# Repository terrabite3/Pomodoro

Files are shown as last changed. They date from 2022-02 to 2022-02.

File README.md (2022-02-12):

# Pomodoro

This is a tomato-shaped timer that counts down from 25 minutes.

## Hardware

* ATmega328p or compatible (I used ATmega8 due to supply chain issues)
* USB Micro-B power
* Four-digit 7-segment multiplexed display with colon LEDs
* Reset button
* Wheel potentiometer to adjust brightness
* Extra GPIO is exposed on a header
* Designed to be mostly assembled by JLCPCB

## Software

* Hard-coded 25 minute countdown
* Flashes 00:00 for one minute after countdown finishes
* Full shutdown after count is complete to save power
* Brightness adjustment goes down "off" to reduce visual distraction. At the start of the countdown, the display will start on and fade down to the selected brightness after 10 seconds. The flashing at the end of the countdown ignores the brightness setting.

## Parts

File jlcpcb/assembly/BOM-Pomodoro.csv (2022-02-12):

Comment | Designator | Footprint | LCSC
1k | R10 | R_0402_1005Metric | C11702
USB_B_Micro | J1 | USB_Micro-B_Amphenol_10118194_Horizontal | C132563
100n | C2,C3 | C_0402_1005Metric | C1525
15p | C4,C5 | C_0402_1005Metric | C1548
10u | C1 | C_0805_2012Metric | C15850
330 | R1,R11,R12,R2,R3,R4,R5,R6,R7,R8 | R_0402_1005Metric | C25104
10k | R9 | R_0402_1005Metric | C25744
2N7002 | Q1,Q2,Q3,Q4 | SOT-23 | C8545
Crystal_GND24 | Y1 | Crystal_SMD_3225-4Pin_3.2x2.5mm | C9002

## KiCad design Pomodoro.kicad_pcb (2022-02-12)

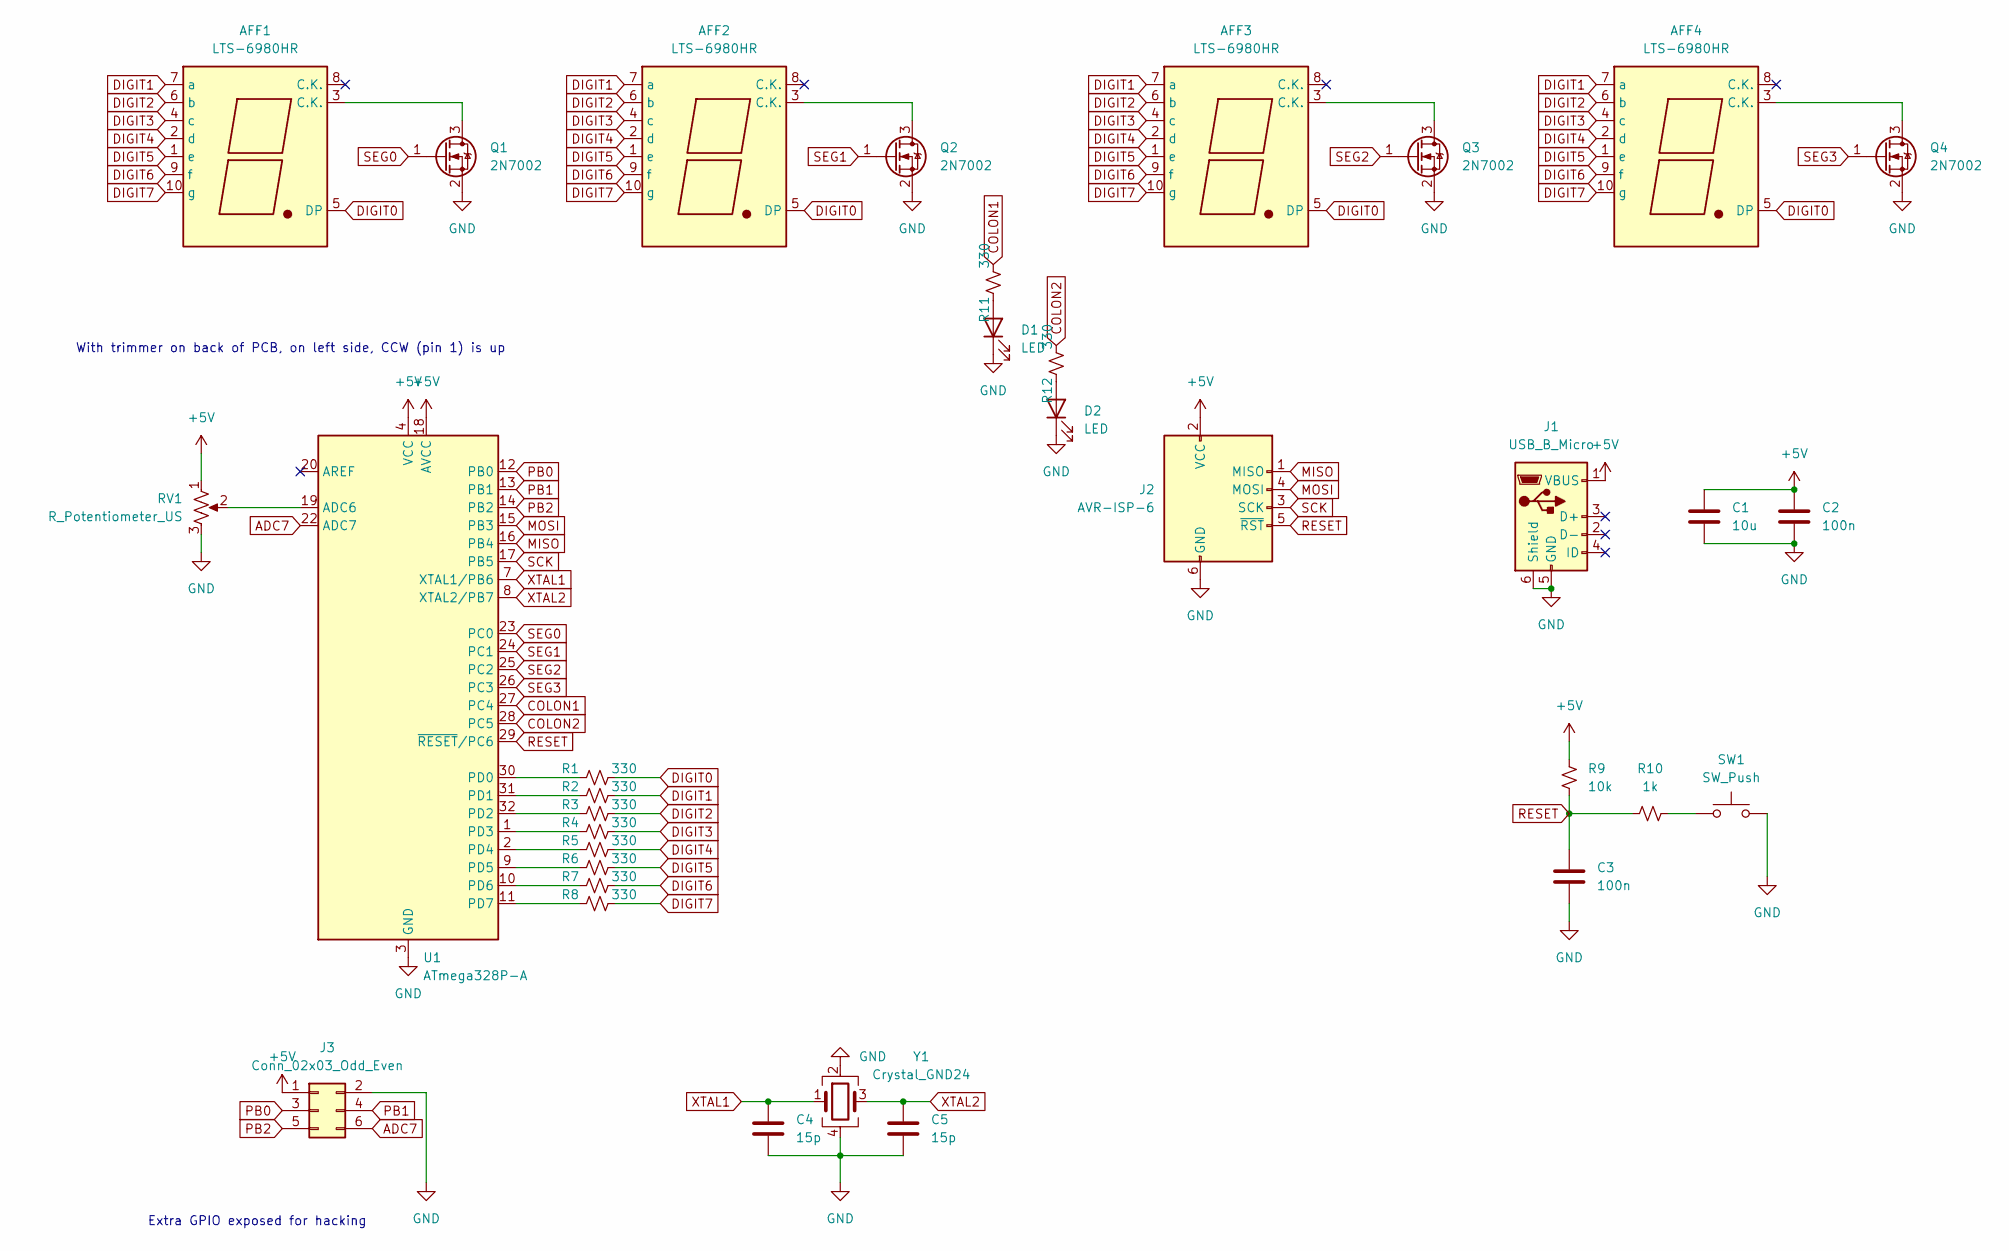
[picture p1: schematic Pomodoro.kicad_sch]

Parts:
AFF1, AFF2, AFF3, AFF4: LTS-6980HR; 7SegmentLED_LTS6760_LTS6780
C1: 10u; C_0805_2012Metric
C2, C3: 100n; C_0402_1005Metric
C4, C5: 15p; C_0402_1005Metric
D1, D2: LED; LED_D3.0mm
J1: USB_B_Micro; USB_Micro-B_Amphenol_10118194_Horizontal
J2: AVR-ISP-6; PinHeader_2x03_P2.54mm_Vertical_SMD
J3: Conn_02x03_Odd_Even; PinHeader_2x03_P2.54mm_Vertical_SMD
Q1, Q2, Q3, Q4: 2N7002; SOT-23
R1, R2, R3, R4, R5, R6, R7, R8, R11, R12: 330; R_0402_1005Metric
R9: 10k; R_0402_1005Metric
R10: 1k; R_0402_1005Metric
RV1: R_Potentiometer_US; Potentiometer_Bourns_3352T
SW1: SW_Push; SW_PUSH_6mm
U1: ATmega328P-A; TQFP-32_7x7mm_P0.8mm
Y1: Crystal_GND24; Crystal_SMD_3225-4Pin_3.2x2.5mm

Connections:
+5V: C1.1, C2.1, J1.1 (VBUS), J2.2 (VCC), J3.1, R9.2, RV1.1, U1.4 (VCC), U1.6 (VCC), U1.18 (AVCC)
ADC7: J3.6, U1.22 (ADC7)
COLON1: R11.2, U1.27 (PC4)
COLON2: R12.2, U1.28 (PC5)
DIGIT0: AFF1.5 (DP), AFF2.5 (DP), AFF3.5 (DP), AFF4.5 (DP), R1.2
DIGIT1: AFF1.7 (a), AFF2.7 (a), AFF3.7 (a), AFF4.7 (a), R2.2
DIGIT2: AFF1.6 (b), AFF2.6 (b), AFF3.6 (b), AFF4.6 (b), R3.2
DIGIT3: AFF1.4 (c), AFF2.4 (c), AFF3.4 (c), AFF4.4 (c), R4.2
DIGIT4: AFF1.2 (d), AFF2.2 (d), AFF3.2 (d), AFF4.2 (d), R5.2
DIGIT5: AFF1.1 (e), AFF2.1 (e), AFF3.1 (e), AFF4.1 (e), R6.2
DIGIT6: AFF1.9 (f), AFF2.9 (f), AFF3.9 (f), AFF4.9 (f), R7.2
DIGIT7: AFF1.10 (g), AFF2.10 (g), AFF3.10 (g), AFF4.10 (g), R8.2
GND: C1.2, C2.2, C3.2, C4.2, C5.2, D1.1 (K), D2.1 (K), J1.5 (GND), J1.6 (Shield), J2.6 (GND), J3.2, Q1.2 (S), Q2.2 (S), Q3.2 (S), Q4.2 (S), RV1.3, SW1.2, U1.3 (GND), U1.5 (GND), U1.21 (GND), Y1.2, Y1.4
MISO: J2.1 (MISO), U1.16 (PB4)
MOSI: J2.4 (MOSI), U1.15 (PB3)
unnamed: AFF1.3 (C.K.), Q1.3 (D)
unnamed: AFF2.3 (C.K.), Q2.3 (D)
unnamed: AFF3.3 (C.K.), Q3.3 (D)
unnamed: AFF4.3 (C.K.), Q4.3 (D)
unnamed: D1.2 (A), R11.1
unnamed: D2.2 (A), R12.1
unnamed: R10.2, SW1.1
unnamed: R4.1, U1.1 (PD3)
unnamed: R5.1, U1.2 (PD4)
unnamed: R6.1, U1.9 (PD5)
unnamed: R7.1, U1.10 (PD6)
unnamed: R8.1, U1.11 (PD7)
unnamed: RV1.2, U1.19 (ADC6)
unnamed: R1.1, U1.30 (PD0)
unnamed: R2.1, U1.31 (PD1)
unnamed: R3.1, U1.32 (PD2)
PB0: J3.3, U1.12 (PB0)
PB1: J3.4, U1.13 (PB1)
PB2: J3.5, U1.14 (PB2)
RESET: C3.1, J2.5 (~RST), R9.1, R10.1, U1.29 (~RESET/PC6)
SCK: J2.3 (SCK), U1.17 (PB5)
SEG0: Q1.1 (G), U1.23 (PC0)
SEG1: Q2.1 (G), U1.24 (PC1)
SEG2: Q3.1 (G), U1.25 (PC2)
SEG3: Q4.1 (G), U1.26 (PC3)
XTAL1: C4.1, U1.7 (XTAL1/PB6), Y1.1
XTAL2: C5.1, U1.8 (XTAL2/PB7), Y1.3

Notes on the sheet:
Extra GPIO exposed for hacking
With trimmer on back of PCB, on left side, CCW (pin 1) is up

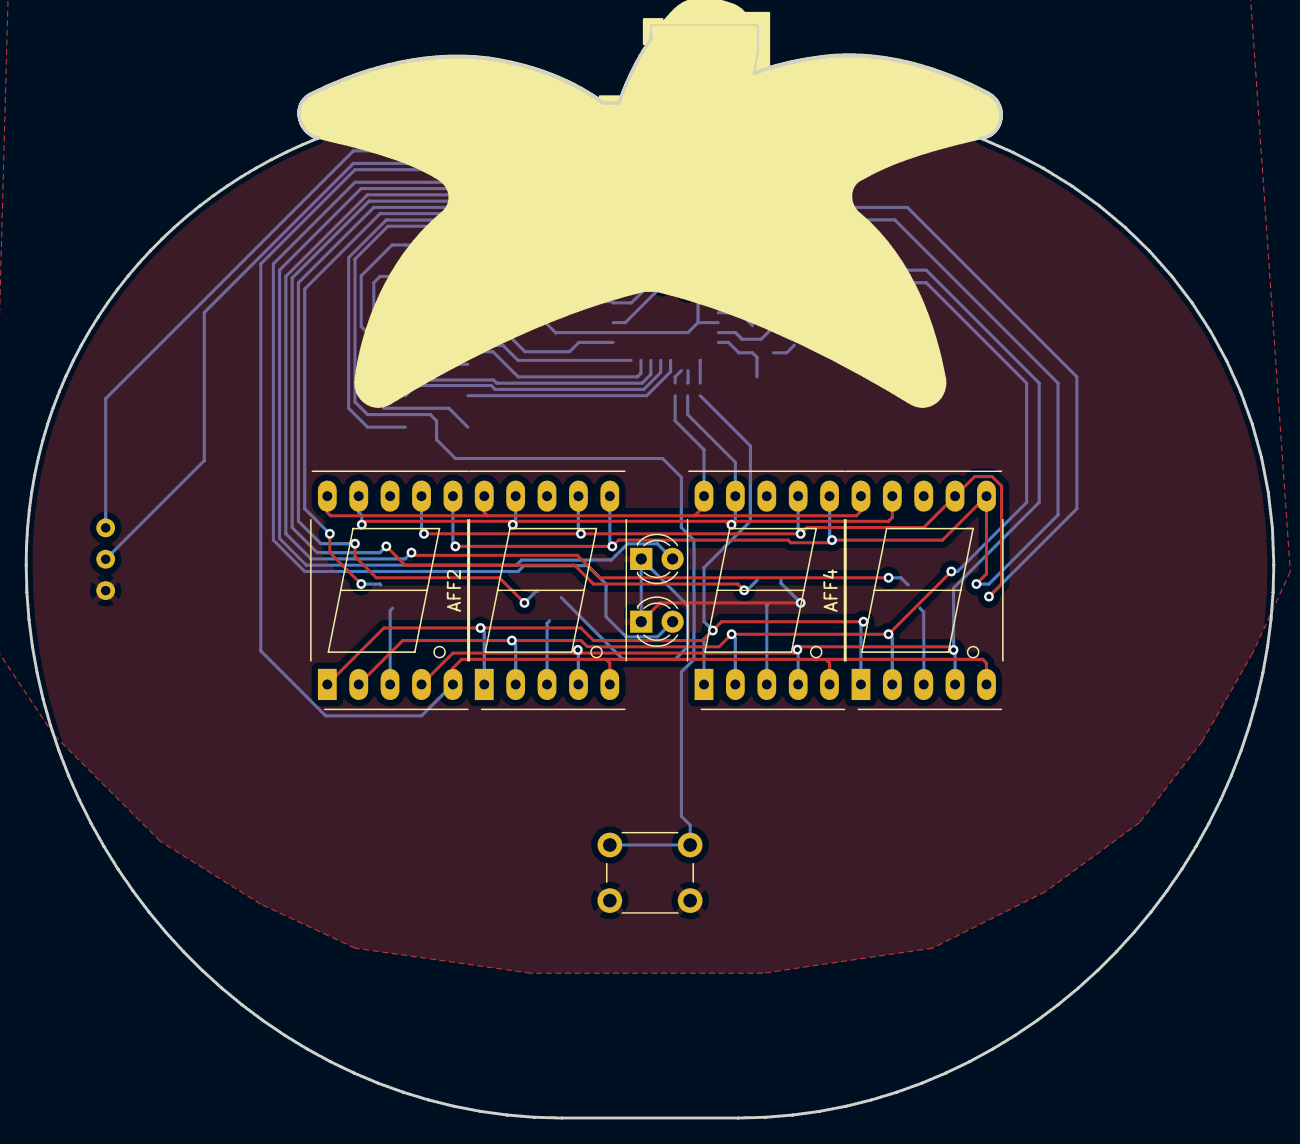
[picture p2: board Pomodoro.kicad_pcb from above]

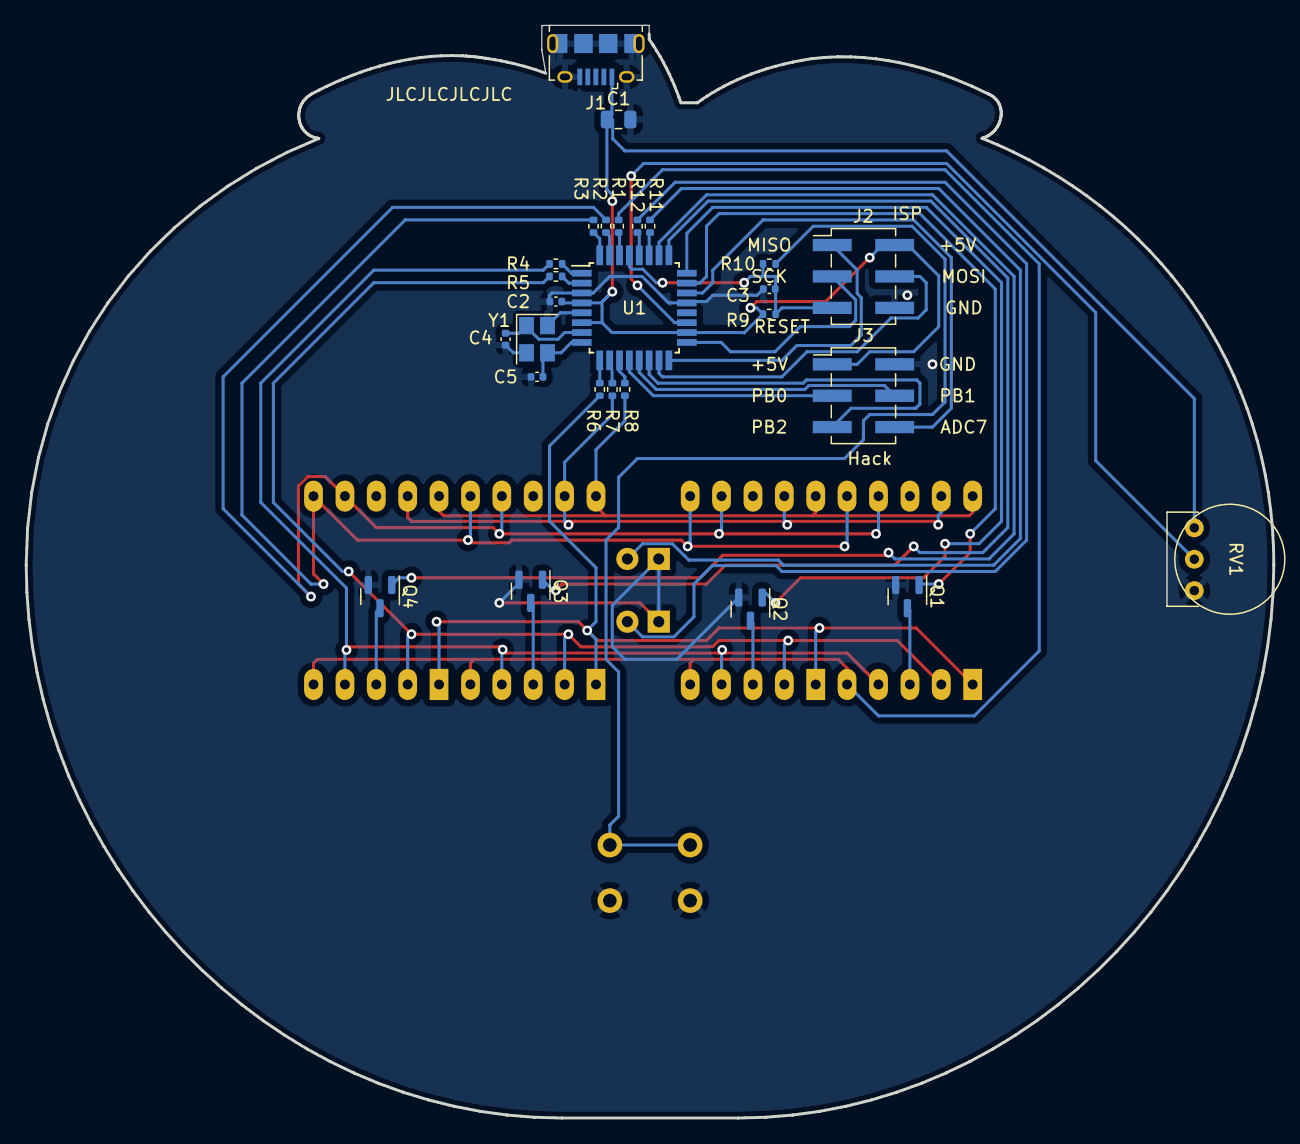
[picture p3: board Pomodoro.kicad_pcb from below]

Board: 2 copper layers, 101.0 x 88.4 mm, 34 parts (27 on the bottom side), 42 nets.

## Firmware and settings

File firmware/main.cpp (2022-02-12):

#include <avr/io.h>
#include <avr/interrupt.h>
#include <avr/sleep.h>

#include <util/delay_basic.h>

/* Pin map

PB0     hack header
PB1     hack header
PB2     hack header
PB3     MOSI (JTAG header)
PB4     MISO (JTAG header)
PB5     SCK (JTAG header)
PB6     XTAL
PB7     XTAL

PC0     SEG0
PC1     SEG1
PC2     SEG2
PC3     SEG3
PC4     COLON1
PC5     COLON2
PC6     RESET (button)

PD0     DIGIT0
...     ...
PD7     DIGIT7

ADC6    pot
ADC7    hack header

*/

#define RESET_TIME 25 * 60

volatile int16_t countdown = RESET_TIME;

ISR(TIMER1_COMPA_vect)
{
    countdown--;
}

void setupTimer()
{
    // setup the timer to fire every 1 second
    
    // Timer count calculated with https://eleccelerator.com/avr-timer-calculator/
    // 12 MHz, 16-bit, Prescaler = Clk/256, Real Time = 1 second
    TCCR1A = 0;         // Nothing needed here
    TCCR1B =  1<<WGM12  // CTC mode (clear timer on compare match)
            | 1<<CS12;  // Clk/256 prescaler
    OCR1A = 46875;

    TIMSK = 1<<OCIE1A;  // Enable the interrupt for output compare A match

    sei(); // Enable global interrupt flag
}

uint8_t digitCode0 = 0;
uint8_t digitCode1 = 0;
uint8_t digitCode2 = 0;
uint8_t digitCode3 = 0;

void noDigit()
{
    PORTC = 0;
}

void nextDigit()
{
    static uint8_t digit = 0;

    digit = (digit + 1) % 4;

    // Reset segment drivers
    PORTC &= ~(1<<PC0 | 1<<PC1 | 1<<PC2 | 1<<PC3);

    switch (digit)
    {
    case 0:
        PORTC |= 1<<PC0;
        PORTD = digitCode0;
        break;
    case 1:
        PORTC |= 1<<PC1;
        PORTD = digitCode1;
        break;
    case 2:
        PORTC |= 1<<PC2;
        PORTD = digitCode2;
        break;
    case 3:
        PORTC |= 1<<PC3;
        PORTD = digitCode3;
        break;
    }
}

uint8_t numberToCode(uint8_t number)
{
    switch (number)
    {
    case 0:
        return 0b01111110;
    case 1:
        return 0b00001100;
    case 2:
        return 0b10110110;
    case 3:
        return 0b10011110;
    case 4:
        return 0b11001100;
    case 5:
        return 0b11011010;
    case 6:
        return 0b11111010;
    case 7:
        return 0b00001110;
    case 8:
        return 0b11111110;
    case 9:
        return 0b11011110;
    case 10: // All off
        return 0b00000000;
    default: // Light decimal point to indicate error
        return 0b00000001;
    }
}

void updateDigits()
{
    // Normal behavior
    if (countdown >= 0)
    {
        uint8_t minutes = countdown / 60;
        uint8_t minutesOnes = minutes % 10;
        uint8_t minutesTens = minutes / 10;

        uint8_t seconds = countdown % 60;
        uint8_t secondsOnes = seconds % 10;
        uint8_t secondsTens = seconds / 10;

        digitCode0 = numberToCode(minutesTens);
        digitCode1 = numberToCode(minutesOnes);
        digitCode2 = numberToCode(secondsTens);
        digitCode3 = numberToCode(secondsOnes);
    }
    // Countdown has underflowed, less than a minute ago
    // Blink 00:00
    else if (countdown >= -60) 
    {
        if (countdown % 2)
        {
            digitCode0 = numberToCode(10);
            digitCode1 = numberToCode(10);
            digitCode2 = numberToCode(10);
            digitCode3 = numberToCode(10);
        }
        else
        {
            digitCode0 = numberToCode(0);
            digitCode1 = numberToCode(0);
            digitCode2 = numberToCode(0);
            digitCode3 = numberToCode(0);
        }
    }
    else
    {
        // Go into low power mode until the reset button is pressed
        cli(); // Disable interrupts

        // Turn off all LEDs and set pins as inputs
        PORTC = 0;
        PORTD = 0;
        DDRC = 0;
        DDRD = 0;

        set_sleep_mode(SLEEP_MODE_PWR_DOWN);
        sleep_mode();
    }
}

int main(void)
{
    setupTimer();

    // AVCC reference, ADC6
    ADMUX = 1<<REFS0 | 6;
    // Enable the ADC, and set it to maximum clock division. We don't need it to be fast.
    ADCSRA = 1<<ADEN | 7;


    DDRC |= 1<<PC0 | 1<<PC1 | 1<<PC2 | 1<<PC3 | 1<<PC4 | 1<<PC5;
    DDRD = 0xFF;

    uint16_t adcValue = 1023;
    while (1)
    {
        // If there isn't currently an ADC conversion, read the value and start a new conversion
        if (!(ADCSRA & (1<<ADSC)))
        {
            adcValue = ADC;
            ADCSRA |= 1<<ADSC;
        }

        updateDigits();

        // If the brightness is turned down, turn it on for the first 10 seconds anyways,
        // dimming over 10 seconds
        if (countdown > RESET_TIME - 10)
        {
            int16_t secondsElapsed = RESET_TIME - countdown;
            int16_t minBrightness = 1023 - 100 * secondsElapsed;
            if (adcValue < minBrightness)
                adcValue = minBrightness;
        }
        // Blink anyways when the countdown ends
        else if (countdown <= 0)
        {
            adcValue = 1023;
        }

        if (adcValue == 0)
        {
            noDigit();
            _delay_loop_2(1024);
        }
        else if (adcValue >= 1023)
        {
            nextDigit();
            _delay_loop_2(1024);
        }
        else
        {
            nextDigit();
            // Keep the digit on for a time determined by the ADC
            _delay_loop_2(adcValue);

            noDigit();
            // Turn off for the inverse
            _delay_loop_2(1024 - adcValue - 1);
        }

    }
}
